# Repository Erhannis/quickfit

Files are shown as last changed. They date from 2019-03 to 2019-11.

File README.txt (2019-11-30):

OpenSCAD translation and modification of RichRap's Quick-Fit X Carriage https://www.thingiverse.com/thing:19590 (CC-A).
I've additionally converted it into a platform for the RepRap Snappy 3 https://github.com/revarbat/snappy-reprap (GPL-2).

Run get_deps.sh to get the dependencies.  (Or, if on windows, create a folder "deps.link" and in it run the git commands given and the bottom of get_deps.sh .)

Everything here that's mine I license under the MIT license.

-Erhannis

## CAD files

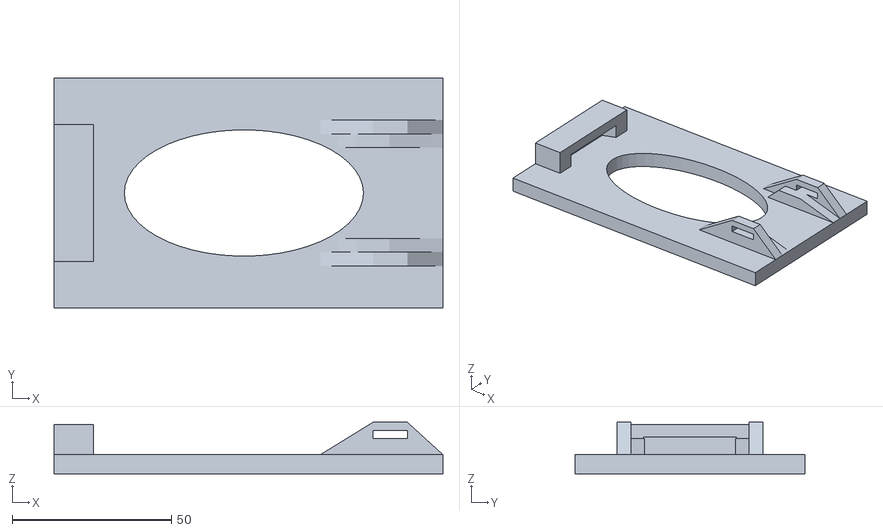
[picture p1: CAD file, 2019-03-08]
quickfit_latch2.stl
122.1 x 72.1 x 16.2

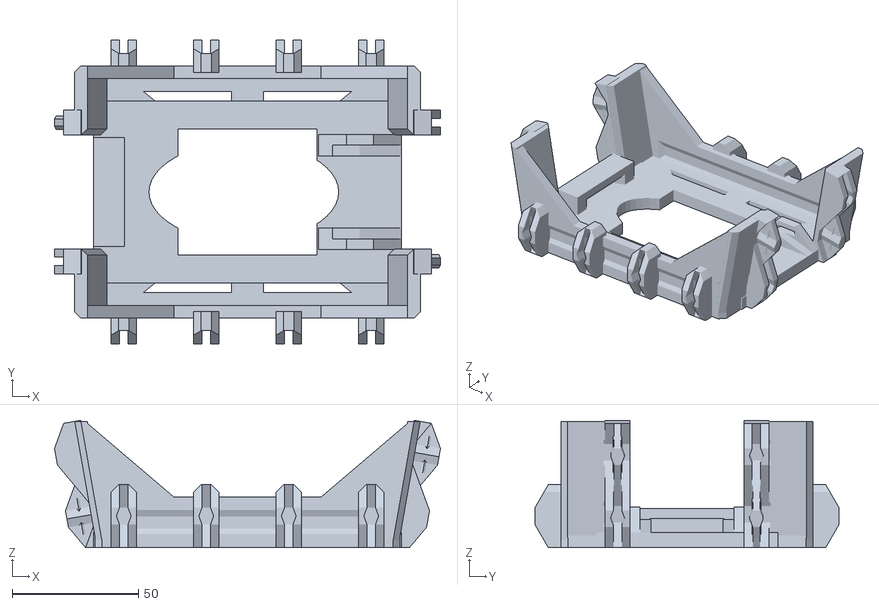
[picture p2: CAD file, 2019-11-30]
snappy_extruder/snappy_quickfit_platform.stl
152.8 x 120.4 x 50.5

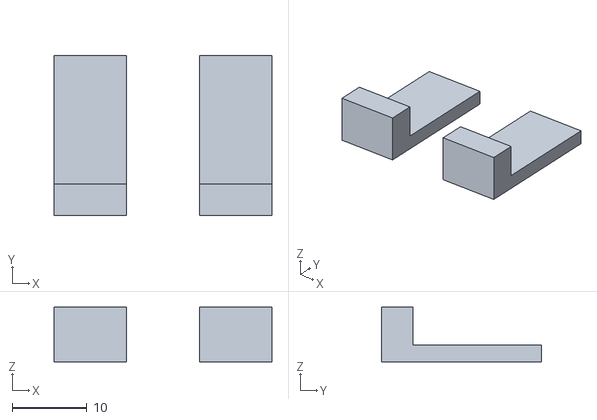
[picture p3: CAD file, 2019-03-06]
latch3.stl
29.2 x 21.5 x 7.35

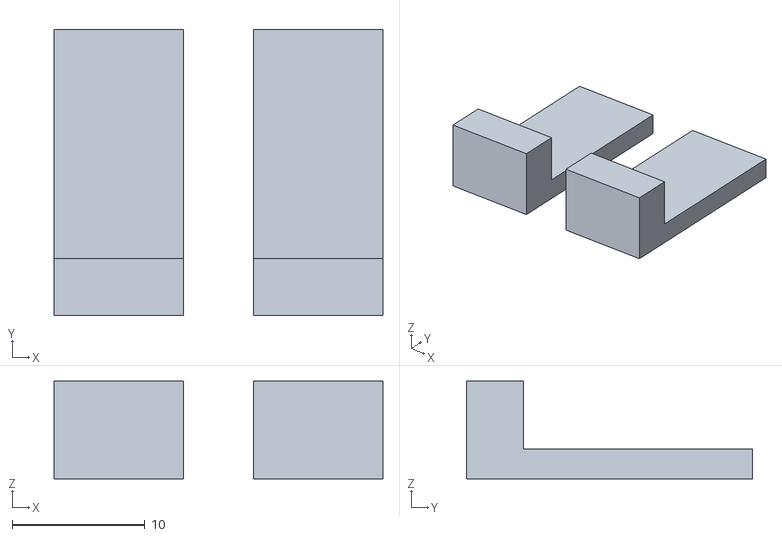
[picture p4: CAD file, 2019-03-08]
snappy_extruder/snappy_quickfit_latch.stl
24.7 x 21.5 x 7.35

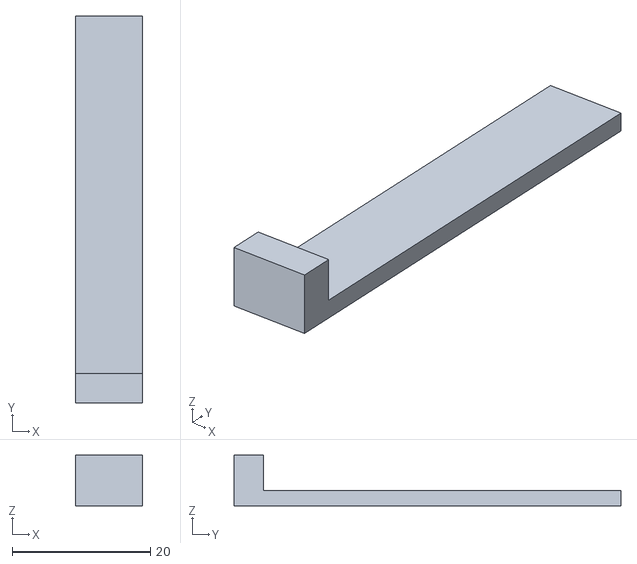
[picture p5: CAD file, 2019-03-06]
latch2.stl
9.75 x 56.0 x 7.35

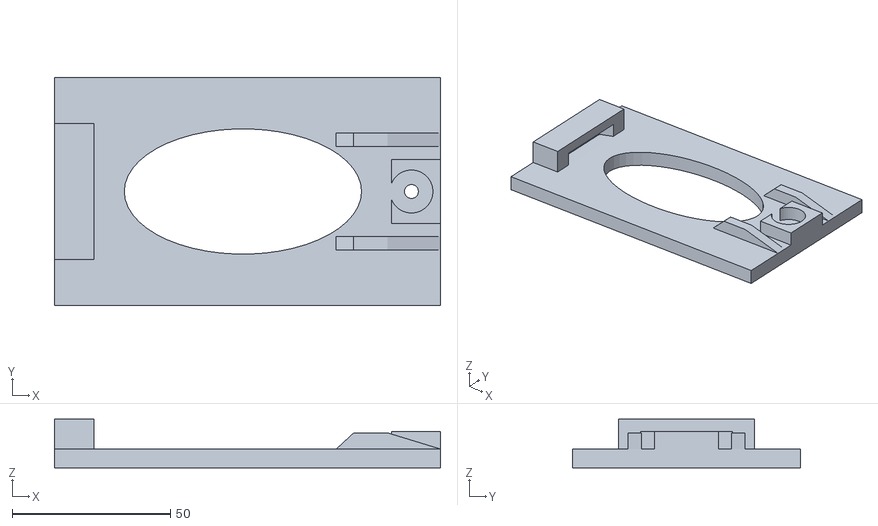
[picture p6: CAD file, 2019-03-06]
quickfit_latch1.stl
122.1 x 72.1 x 15.5

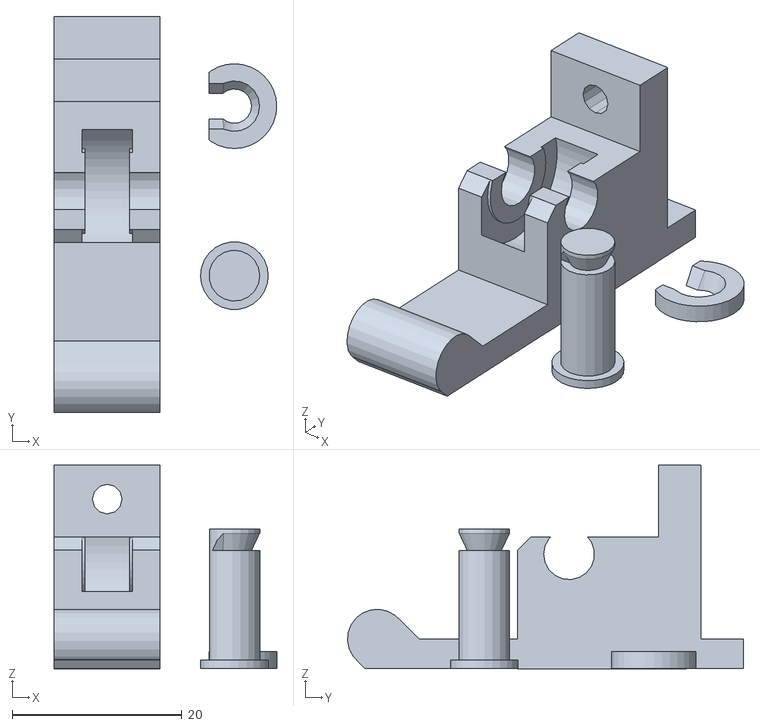
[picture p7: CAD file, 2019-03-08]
snappy_extruder/extruder_idler_parts.stl
26.2 x 46.7 x 24.0

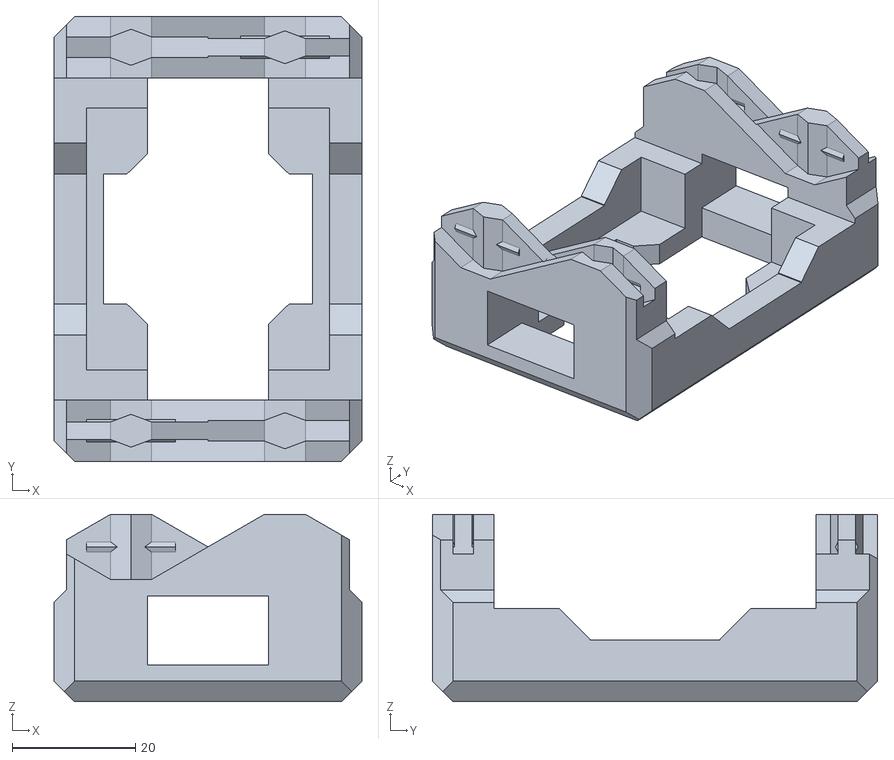
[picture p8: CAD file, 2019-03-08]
snappy_extruder/extruder_motor_clip_parts.stl
50.0 x 72.3 x 30.4

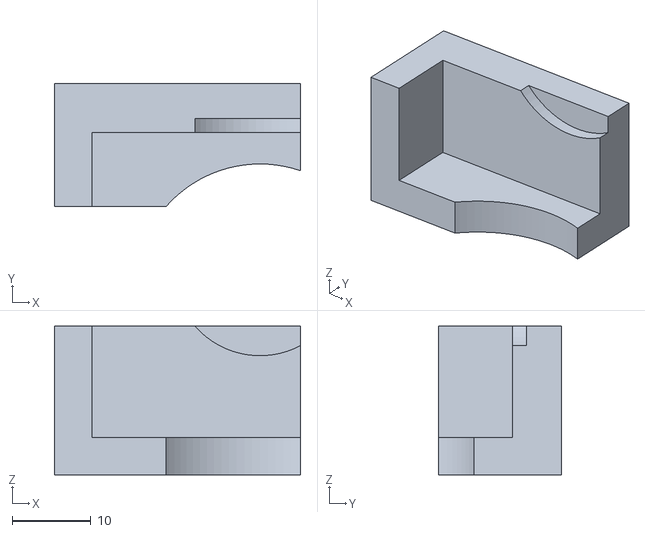
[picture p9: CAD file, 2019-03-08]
snappy_extruder/e3dv6_lock_parts.stl
31.3 x 15.7 x 18.9

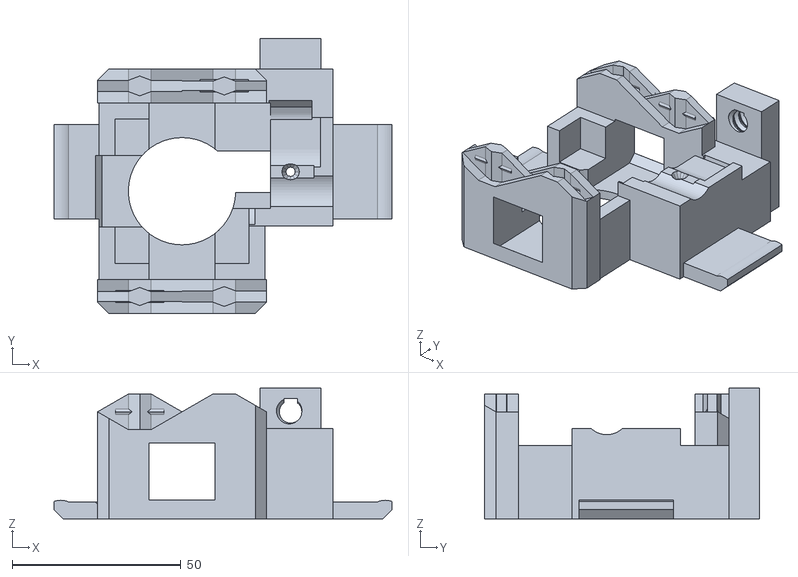
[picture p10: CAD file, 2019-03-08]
snappy_extruder/snappy_quickfit_extruder.stl
100.0 x 81.3 x 38.6

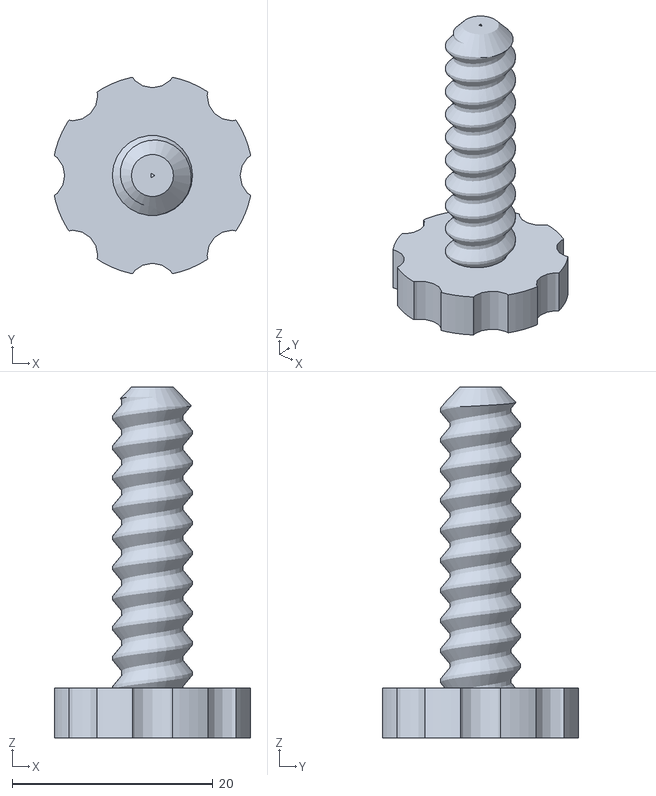
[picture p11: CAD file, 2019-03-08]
snappy_extruder/compression_screw_parts.stl
19.6 x 19.6 x 35.0

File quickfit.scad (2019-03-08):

/*
OpenSCAD reverse engineering of RichRap's Quick-Fit attachment plate.
( https://www.thingiverse.com/thing:19590 )

It's intended to be used in the construction of other x-carriages etc.,
not used on its own - it currently doesn't have any kind of anchor-point.
I plan on making a RepRap Snappy extruder plaform for the quick-fit
attachment.

Note: the hinge doesn't print well, when the model is printed flat.
When I printed it hinge-end-down, standing up, it actually printed decently.
A little rough near the latch, but functional.  I did thicken the plate
from 4.28mm to 6mm, to improve stability while printing.

I've taken most measurements from the STL files, presumably derived from
the SketchUp files, so the numbers are pretty arbitrary-looking.  The
only deviations-from-source I know of are:
1. I stripped off the x-carriage bits
2. Also skipped the zip-tie holes and grooves
3. The shape of the big tool-hole in the middle was somewhat inscrutable, so now it's an ellipse
4. Technically the resolution of the circles may be different
I think everything else should be accurate to within a hundredth of a mm.
*/

$fn = 50;

LATCH_TYPE = 3; // 1=original, 2=bar, 3=multibar

PLATE_SIZE_Z = 6; //4.28
PLATE_SIZE_X = 122.1398;
PLATE_SIZE_Y = 72.09;

HINGE_FLOOR_X = 20.5;

// Side ramps are assumed to end at the edge of the plate
SIDE_RAMP_GAP_Y = 28.6;
SIDE_RAMP_SIZE_Y = 4.275;
SIDE_RAMP_SIZE_Z = 5.1;
SIDE_RAMP_1_SIZE_X = 5.5267; // Short one near center
SIDE_RAMP_2_SIZE_X = 10.7464; // Flat segment
SIDE_RAMP_3_SIZE_X = 16.7225; // Long one near edge


// Latch type 1
LATCH_SEAT_SMALL_HOLE_DIAM = 4.4;
LATCH_SEAT_BIG_HOLE_DIAM = 13.5983;
LATCH_SEAT_HOLE_X_OFFSET = 6.2733;
LATCH_SEAT_SIZE_X = 15.4733;
LATCH_SEAT_SIZE_Y = LATCH_SEAT_BIG_HOLE_DIAM*1.5;//TODO
LATCH_SEAT_SIZE_Z = 5.6;

// Latch type 2
BRACKET_SKEW_X = 1*SIDE_RAMP_1_SIZE_X;
BRACKET_1_SIZE_X = 2*SIDE_RAMP_1_SIZE_X;// + BRACKET_SKEW_X;
BRACKET_3_SIZE_X = SIDE_RAMP_3_SIZE_X - BRACKET_SKEW_X;
BRACKET_SIZE_Z = 2*SIDE_RAMP_SIZE_Z;
BRACKET_TOP_SIZE_Z = (BRACKET_SIZE_Z - SIDE_RAMP_SIZE_Z) / 2;
BRACKET_LATCH_SIZE_X = SIDE_RAMP_2_SIZE_X - 1;
BRACKET_LATCH_SIZE_Y = SIDE_RAMP_GAP_Y + (4*SIDE_RAMP_SIZE_Y) + 6;
BRACKET_LATCH_SIZE_Z = BRACKET_SIZE_Z - SIDE_RAMP_SIZE_Z - BRACKET_TOP_SIZE_Z - 0.3;
BRACKET_LATCH_HANDLE_SIZE_Z = BRACKET_LATCH_SIZE_Z + (2*BRACKET_TOP_SIZE_Z);

// Latch type 3
BRACKET_LATCH_3_SIZE_Y = BRACKET_LATCH_SIZE_Y/3;


TOOL_HOLE_SIZE_Y = 39.65;
TOOL_HOLE_HINGE_X = 22.077;
TOOL_HOLE_LATCH_X = 24.9733;
TOOL_HOLE_SIZE_X = PLATE_SIZE_X - TOOL_HOLE_HINGE_X - TOOL_HOLE_LATCH_X;

HINGE_OUTER_SIZE_X = 12.42;
HINGE_OUTER_SIZE_Y = 43.15;
HINGE_OUTER_SIZE_Z = 9.5 + PLATE_SIZE_Z;

// Some of these params may not lead to reasonable results if other params are changed - it's kindof a complicated shape, and I haven't worked out the most robustly sensical representation.  Particularly the circular cutout in the hinge.
HINGE_INNER_SIZE_Y = 29.22;
HINGE_INNER_BLOCK_SIZE_X = 7;
HINGE_OVERHANG_SIZE_Z = 4;
HINGE_INNER_BLOCK_SIZE_Z = HINGE_OUTER_SIZE_Z - PLATE_SIZE_Z - HINGE_OVERHANG_SIZE_Z;
HINGE_CIRCLE_CUTOUT_DIAMETER = 10.4;
HINGE_CIRCLE_CUTOUT_REGION_X = 4;
HINGE_CIRCLE_CUTOUT_OFFSET_Z = 0.7;
HINGE_RAMP_SIZE_Z = 1.5;

module quickfit() {
  difference() {
    union() {
      { // Plate
        cube([PLATE_SIZE_X, PLATE_SIZE_Y, PLATE_SIZE_Z]);
      }
      { // Latch seat
        if (LATCH_TYPE == 1) {
          translate([PLATE_SIZE_X-LATCH_SEAT_SIZE_X, (PLATE_SIZE_Y-LATCH_SEAT_SIZE_Y)/2, PLATE_SIZE_Z]) {
            difference() {
              cube([LATCH_SEAT_SIZE_X, LATCH_SEAT_SIZE_Y, LATCH_SEAT_SIZE_Z]);
              translate([LATCH_SEAT_HOLE_X_OFFSET, LATCH_SEAT_SIZE_Y/2, 0]) {
                cylinder(d=LATCH_SEAT_BIG_HOLE_DIAM, h=LATCH_SEAT_SIZE_Z);
              };
            };
          };
        } else if (LATCH_TYPE == 2 || LATCH_TYPE == 3) {
          // (Derived from side ramps)
          for (i = [-1,1]) {
            translate([0, i * (((SIDE_RAMP_GAP_Y+SIDE_RAMP_SIZE_Y)/2)+SIDE_RAMP_SIZE_Y), 0]) {
              translate([PLATE_SIZE_X - BRACKET_1_SIZE_X - SIDE_RAMP_2_SIZE_X - BRACKET_3_SIZE_X, (PLATE_SIZE_Y - SIDE_RAMP_SIZE_Y)/2, PLATE_SIZE_Z]) {
                translate([0,0,0]) {
                  scale([BRACKET_1_SIZE_X, SIDE_RAMP_SIZE_Y, BRACKET_SIZE_Z]) {
                    difference() {
                      cube(1);
                      rotate([0,-45,0])
                        cube(2);
                    }
                  }
                }
                translate([BRACKET_1_SIZE_X,0,0]) {
                  cube([SIDE_RAMP_2_SIZE_X,SIDE_RAMP_SIZE_Y,SIDE_RAMP_SIZE_Z]);
                }
                translate([BRACKET_1_SIZE_X,0,BRACKET_SIZE_Z-BRACKET_TOP_SIZE_Z]) {
                  cube([SIDE_RAMP_2_SIZE_X,SIDE_RAMP_SIZE_Y,BRACKET_TOP_SIZE_Z]);
                }
                translate([BRACKET_1_SIZE_X+SIDE_RAMP_2_SIZE_X,0,0]) {
                  scale([BRACKET_3_SIZE_X, SIDE_RAMP_SIZE_Y, BRACKET_SIZE_Z]) {
                    translate([0,0,1])
                    rotate([0,90,0])
                    difference() {
                      cube(1);
                      rotate([0,-45,0])
                        cube(2);
                    }
                  }
                }
              }
            }
          }
        }
      }
      { // Side ramps
        for (i = [-1,1]) {
          translate([0, i * ((SIDE_RAMP_GAP_Y+SIDE_RAMP_SIZE_Y)/2), 0]) {
            translate([PLATE_SIZE_X - SIDE_RAMP_1_SIZE_X - SIDE_RAMP_2_SIZE_X - SIDE_RAMP_3_SIZE_X, (PLATE_SIZE_Y - SIDE_RAMP_SIZE_Y)/2, PLATE_SIZE_Z]) {
              translate([0,0,0]) {
                scale([SIDE_RAMP_1_SIZE_X, SIDE_RAMP_SIZE_Y, SIDE_RAMP_SIZE_Z]) {
                  difference() {
                    cube(1);
                    rotate([0,-45,0])
                      cube(2);
                  }
                }
              }
              translate([SIDE_RAMP_1_SIZE_X,0,0]) {
                cube([SIDE_RAMP_2_SIZE_X,SIDE_RAMP_SIZE_Y,SIDE_RAMP_SIZE_Z]);
              }
              translate([SIDE_RAMP_1_SIZE_X+SIDE_RAMP_2_SIZE_X,0,0]) {
                scale([SIDE_RAMP_3_SIZE_X, SIDE_RAMP_SIZE_Y, SIDE_RAMP_SIZE_Z]) {
                  translate([0,0,1])
                  rotate([0,90,0])
                  difference() {
                    cube(1);
                    rotate([0,-45,0])
                      cube(2);
                  }
                }
              }
            }
          }
        }
      }
      { // Hinge additive
        translate([0, (PLATE_SIZE_Y-HINGE_OUTER_SIZE_Y)/2, 0])
          cube([HINGE_OUTER_SIZE_X, HINGE_OUTER_SIZE_Y, HINGE_OUTER_SIZE_Z]);
      }
    };
    if (LATCH_TYPE == 1) { // Latch hole
      translate([PLATE_SIZE_X-LATCH_SEAT_SIZE_X, (PLATE_SIZE_Y-LATCH_SEAT_SIZE_Y)/2, 0]) {
        translate([LATCH_SEAT_HOLE_X_OFFSET, LATCH_SEAT_SIZE_Y/2, 0]) {
          cylinder(d=LATCH_SEAT_SMALL_HOLE_DIAM, h=PLATE_SIZE_Z);
        };
      };
    }
    { // Tool hole
      // This isn't exactly the (arcane) shape of the original, but maybe it's close enough.
      translate([TOOL_HOLE_HINGE_X, (PLATE_SIZE_Y-TOOL_HOLE_SIZE_Y)/2, 0]) {
        translate([TOOL_HOLE_SIZE_X/2, TOOL_HOLE_SIZE_Y/2, 0]) {
          scale([TOOL_HOLE_SIZE_X, TOOL_HOLE_SIZE_Y, PLATE_SIZE_Z]){
            cylinder(d=1,h=1);
          }
        }
      }
    }
    { // Hinge subtractive
      translate([HINGE_OUTER_SIZE_X-HINGE_INNER_BLOCK_SIZE_X, (PLATE_SIZE_Y-HINGE_INNER_SIZE_Y)/2, PLATE_SIZE_Z]) {
        union() {
          cube([HINGE_INNER_BLOCK_SIZE_X, HINGE_INNER_SIZE_Y, HINGE_INNER_BLOCK_SIZE_Z]);
          translate([0,0,HINGE_CIRCLE_CUTOUT_OFFSET_Z])
            intersection() {
              translate([HINGE_CIRCLE_CUTOUT_REGION_X/2, 0, 0])
                rotate([-90,0,0])
                  cylinder(d=HINGE_CIRCLE_CUTOUT_DIAMETER, h=HINGE_INNER_SIZE_Y);
              cube([HINGE_CIRCLE_CUTOUT_REGION_X, HINGE_INNER_SIZE_Y, HINGE_CIRCLE_CUTOUT_DIAMETER]);
            };
          scale([HINGE_INNER_BLOCK_SIZE_X, 1, HINGE_RAMP_SIZE_Z])
            translate([0,0,-1])
              difference() {
                cube([1, HINGE_INNER_SIZE_Y, 1]);
                rotate([0, 45, 0])
                  cube([2, HINGE_INNER_SIZE_Y, 2]);
              };
        }
      }
    }
    /*
    { // Debug cross-section
      cube([PLATE_SIZE_X, 30, 50]);
      translate([0, 31, 0])
        cube([PLATE_SIZE_X, 300, 50]);
    }
    */
  };
};

module latchType2() {
  cube([BRACKET_LATCH_SIZE_X, BRACKET_LATCH_SIZE_Y, BRACKET_LATCH_SIZE_Z]);
  translate([0, -SIDE_RAMP_SIZE_Y])
    cube([BRACKET_LATCH_SIZE_X, SIDE_RAMP_SIZE_Y, BRACKET_LATCH_HANDLE_SIZE_Z]);
};

module latchType3() {
  cube([BRACKET_LATCH_SIZE_X, BRACKET_LATCH_3_SIZE_Y, BRACKET_LATCH_SIZE_Z]);
  translate([0, -SIDE_RAMP_SIZE_Y])
    cube([BRACKET_LATCH_SIZE_X, SIDE_RAMP_SIZE_Y, BRACKET_LATCH_HANDLE_SIZE_Z]);
};

quickfit();
//latchType2();
//latchType3();

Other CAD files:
quickfit.stl
snappy_extruder/snappy_quickfit_platform_parts.scad

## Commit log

2019-03-04 Initial commit, possibly final commit. Converted RichRap's Quick-Fit to OpenSCAD.
    [quickfit.scad]
2019-03-05 Got a working print, printed hinge-end-down.
    [quickfit.scad, quickfit.stl]
2019-03-06 Added as second kind of latch - a bar, so you can print the whole thing!
    [latch2.stl, quickfit.scad, quickfit_latch1.stl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]
2019-03-06 Slightly thinner bracket latch, because of friction problems.
    [latch2.stl, quickfit.scad]
2019-03-06 Added a 3rd latch type, a bar latch but two smaller ones to work around limited y-space, where you don't have room to slide a whole bar out.
    [latch3.stl, quickfit.scad]
2019-03-08 Shifted bracket back a bit, to be out of the way of the paste extruder motor.
    [quickfit.scad, quickfit_latch2.stl]
2019-03-08 Added a Snappy quickfit platform, and extruder attachment
    [blank_plate.scad, blank_plate.stl, compression_screw_parts.stl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]
2019-11-30 Looks like a few months ago I cut a rectangle out of the platform to have more room to work with.
    [snappy_quickfit_platform.stl, snappy_quickfit_platform_parts.scad]
2019-11-30 Switched to dependencies
    [blank_plate.scad, blank_plate.stl, snappy_quickfit_platform_parts.scad]
2019-11-30 Added README
    [snappy_quickfit_platform_parts.scad]
